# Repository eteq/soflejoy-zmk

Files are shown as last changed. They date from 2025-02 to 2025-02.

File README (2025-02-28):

# Soflejoy

This is a mod on a Sofle Choc keyboard that replaces the right-side encoder with a joystick.  The PCB layout for the adapter board is a KiCad PCB in ``joystick_encoder_adapter``. The joystick is a FJ06K-S joystick and you can just solder that into the adapter board and then use short lengths of wire to connect the adapter to the encoder footprint. Note, though, there is not a power pin available on the existing Sofle layout, so you will need to do a little bodge wire connecting the 3V pad on the adapter to the nearby 3V pad for the power jack that connects the two halves of the keyboard.

## Building

In zmk dir, start devcontainer as:

% devcontainer up --workspace-folder ~/src/zmk && devcontainer exec --workspace-folder ~/src/zmk bash

Then in the devcontainer:

% cd app
% west build -d build/left -b nice_nano_v2 -- -DSHIELD=soflejoy_left -DZMK_CONFIG=/workspaces/zmk-config -DZMK_EXTRA_MODULES=/workspaces/zmk-config && west build -d build/right -b nice_nano_v2 -- -DSHIELD=soflejoy_right -DZMK_CONFIG=/workspaces/zmk-config -DZMK_EXTRA_MODULES=/workspaces/zmk-config

But that only works if the zmk-config volume is set up to point to this directory.

## Joystick calibration

For in-min/max/deadzone values I set are probably dependent on the specific joystick. To determine them I compiled the right board with ``-S zmk-usb-logging``, set ``config INPUT_LOG_LEVEL=4`` in the defconfig, and then fiddled with the joystick while saving out the ttyACM0 output.  I then parsed the raw values with some manual python to get the resulting values. For my particular joystick I saw:

* both x and y would max out at ~4000 if you just scrolled them, but if you wiped them, went up to ~4050
* x and y both mined out within 10 or so of 0, although x consistently at -3, and y either 10 or -3 depending on wiping
* x at center seemed to be 2010 - 2030
* y at center seemed to be 1780 - 2100 - i.e. didn't bounce back to the same spot
* std at stability was ~4

## Modifying the keymap

The keymap is configured via the ``boards/shields/soflejoy/sofle_keymaps.xlsx file``.  Once updated, run ``python make_map.py -f sofle_keymaps.xlsx > soflejoy.keymap`` to update the keymap.

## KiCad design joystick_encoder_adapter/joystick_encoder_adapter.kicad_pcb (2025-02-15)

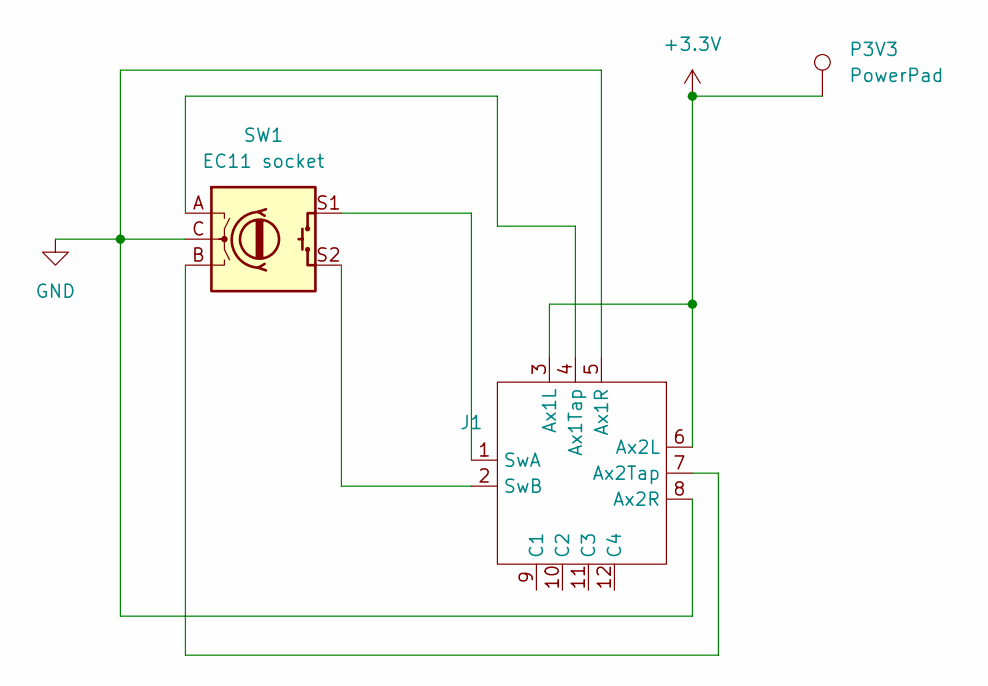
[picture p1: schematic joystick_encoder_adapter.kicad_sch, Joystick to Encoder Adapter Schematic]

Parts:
J1: FJ06K
P3V3: PowerPad; TestPoint_THTPad_D2.0mm_Drill1.0mm
SW1: EC11 socket; ec11e_from_sofle_nomp

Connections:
+3.3V: J1.3 (Ax1L), J1.6 (Ax2L), P3V3.1
GND: J1.5 (Ax1R), J1.8 (Ax2R), SW1.C
unnamed: J1.4 (Ax1Tap), SW1.A
unnamed: J1.7 (Ax2Tap), SW1.B
unnamed: J1.1 (SwA), SW1.S1
unnamed: J1.2 (SwB), SW1.S2

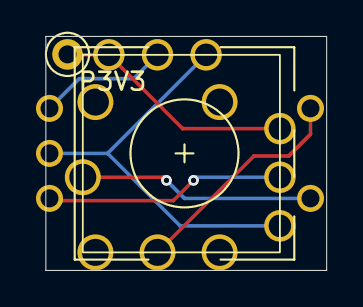
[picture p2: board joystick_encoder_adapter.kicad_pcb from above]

Board: 2 copper layers, 15.6 x 13.0 mm, 3 parts (0 on the bottom side), 6 nets.

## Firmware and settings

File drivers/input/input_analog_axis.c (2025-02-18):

/*
 * Copyright 2023 Google LLC
 *
 * SPDX-License-Identifier: Apache-2.0
 */

#define DT_DRV_COMPAT analog_axis

#include <stdlib.h>
#include <zephyr/device.h>
#include <zephyr/drivers/adc.h>
#include <zephyr/input/input.h>
#include <zephyr/input/input_analog_axis.h>
#include <zephyr/kernel.h>
#include <zephyr/logging/log.h>
#include <zephyr/pm/device.h>
#include <zephyr/pm/device_runtime.h>
#include <zephyr/sys/atomic.h>
#include <zephyr/sys/util.h>

LOG_MODULE_REGISTER(analog_axis, CONFIG_INPUT_LOG_LEVEL);

struct analog_axis_channel_config {
	struct adc_dt_spec adc;
	int16_t out_min;
	int16_t out_max;
	uint16_t axis;
	bool invert_input;
	bool invert_output;
	bool relative_axis;
};

struct analog_axis_channel_data {
	int last_out;
};

struct analog_axis_config {
	uint32_t poll_period_ms;
	const struct analog_axis_channel_config *channel_cfg;
	struct analog_axis_channel_data *channel_data;
	struct analog_axis_calibration *calibration;
	const uint8_t num_channels;
};

struct analog_axis_data {
	struct k_sem cal_lock;
	analog_axis_raw_data_t raw_data_cb;
	struct k_timer timer;
	struct k_thread thread;

	K_KERNEL_STACK_MEMBER(thread_stack,
			      CONFIG_INPUT_ANALOG_AXIS_THREAD_STACK_SIZE);

#ifdef CONFIG_PM_DEVICE
	atomic_t suspended;
	struct k_sem wakeup;
#endif
};

int analog_axis_num_axes(const struct device *dev)
{
	const struct analog_axis_config *cfg = dev->config;

	return cfg->num_channels;
}

int analog_axis_calibration_get(const struct device *dev,
				int channel,
				struct analog_axis_calibration *out_cal)
{
	const struct analog_axis_config *cfg = dev->config;
	struct analog_axis_data *data = dev->data;
	struct analog_axis_calibration *cal = &cfg->calibration[channel];

	if (channel >= cfg->num_channels) {
		return -EINVAL;
	}

	k_sem_take(&data->cal_lock, K_FOREVER);
	memcpy(out_cal, cal, sizeof(struct analog_axis_calibration));
	k_sem_give(&data->cal_lock);

	return 0;
}

void analog_axis_set_raw_data_cb(const struct device *dev, analog_axis_raw_data_t cb)
{
	struct analog_axis_data *data = dev->data;

	k_sem_take(&data->cal_lock, K_FOREVER);
	data->raw_data_cb = cb;
	k_sem_give(&data->cal_lock);
}

int analog_axis_calibration_set(const struct device *dev,
				int channel,
				struct analog_axis_calibration *new_cal)
{
	const struct analog_axis_config *cfg = dev->config;
	struct analog_axis_data *data = dev->data;
	struct analog_axis_calibration *cal = &cfg->calibration[channel];

	if (channel >= cfg->num_channels) {
		return -EINVAL;
	}

	k_sem_take(&data->cal_lock, K_FOREVER);
	memcpy(cal, new_cal, sizeof(struct analog_axis_calibration));
	k_sem_give(&data->cal_lock);

	return 0;
}

static int32_t analog_axis_out_deadzone(const struct device *dev,
					int channel,
					int32_t raw_val)
{
	const struct analog_axis_config *cfg = dev->config;
	const struct analog_axis_channel_config *axis_cfg = &cfg->channel_cfg[channel];
	struct analog_axis_calibration *cal = &cfg->calibration[channel];

	int16_t in_range = cal->in_max - cal->in_min;
	int16_t out_range = axis_cfg->out_max - axis_cfg->out_min;
	int16_t in_mid = DIV_ROUND_CLOSEST(cal->in_min + cal->in_max, 2);
	int16_t in_min = cal->in_min;

	if (abs(raw_val - in_mid) < cal->in_deadzone) {
		return DIV_ROUND_CLOSEST(axis_cfg->out_max + axis_cfg->out_min, 2);
	}

	in_range -= cal->in_deadzone * 2;
	in_min += cal->in_deadzone;
	if (raw_val < in_mid) {
		raw_val += cal->in_deadzone;
	} else {
		raw_val -= cal->in_deadzone;
	}

	return DIV_ROUND_CLOSEST((raw_val - in_min) * out_range, in_range) + axis_cfg->out_min;
}

static int32_t analog_axis_out_linear(const struct device *dev,
				      int channel,
				      int32_t raw_val)
{
	const struct analog_axis_config *cfg = dev->config;
	const struct analog_axis_channel_config *axis_cfg = &cfg->channel_cfg[channel];
	struct analog_axis_calibration *cal = &cfg->calibration[channel];

	int16_t in_range = cal->in_max - cal->in_min;
	int16_t out_range = axis_cfg->out_max - axis_cfg->out_min;

	return DIV_ROUND_CLOSEST((raw_val - cal->in_min) * out_range, in_range) + axis_cfg->out_min;
}

static void analog_axis_loop(const struct device *dev)
{
	const struct analog_axis_config *cfg = dev->config;
	struct analog_axis_data *data = dev->data;
	int16_t bufs[cfg->num_channels];
	int32_t out;
	struct adc_sequence sequence = {
		.buffer = bufs,
		.buffer_size = sizeof(bufs),
	};
	const struct analog_axis_channel_config *axis_cfg_0 = &cfg->channel_cfg[0];
	int err;
	int i;

	adc_sequence_init_dt(&axis_cfg_0->adc, &sequence);

	for (i = 0; i < cfg->num_channels; i++) {
		const struct analog_axis_channel_config *axis_cfg = &cfg->channel_cfg[i];

		sequence.channels |= BIT(axis_cfg->adc.channel_id);
	}

	err = adc_read(axis_cfg_0->adc.dev, &sequence);
	if (err < 0) {
		LOG_ERR("Could not read (%d)", err);
		return;
	}

	k_sem_take(&data->cal_lock, K_FOREVER);

	for (i = 0; i < cfg->num_channels; i++) {
		const struct analog_axis_channel_config *axis_cfg = &cfg->channel_cfg[i];
		struct analog_axis_channel_data *axis_data = &cfg->channel_data[i];
		struct analog_axis_calibration *cal = &cfg->calibration[i];
		int32_t raw_val = bufs[i];

		if (axis_cfg->invert_input) {
			raw_val *= -1;
		}

		if (data->raw_data_cb != NULL) {
			data->raw_data_cb(dev, i, raw_val);
		}

		LOG_DBG("%s: ch %d: raw_val: %d", dev->name, i, raw_val);

		if (cal->in_deadzone > 0) {
			out = analog_axis_out_deadzone(dev, i, raw_val);
		} else {
			out = analog_axis_out_linear(dev, i, raw_val);
		}

		out = CLAMP(out, axis_cfg->out_min, axis_cfg->out_max);

		if (axis_cfg->invert_output) {
			out = axis_cfg->out_max - out;
		}

		if (axis_cfg->relative_axis) {
			if (axis_data->last_out != 0 || out != 0) {  // not sure if the last out is needed
				input_report_rel(dev, axis_cfg->axis, out, true, K_FOREVER);
			}
		} else {
			if (axis_data->last_out != out) {
				input_report_abs(dev, axis_cfg->axis, out, true, K_FOREVER);
			}
		}
		axis_data->last_out = out;
	}

	k_sem_give(&data->cal_lock);
}

static void analog_axis_thread(void *arg1, void *arg2, void *arg3)
{
	const struct device *dev = arg1;
	const struct analog_axis_config *cfg = dev->config;
	struct analog_axis_data *data = dev->data;
	int err;
	int i;

	for (i = 0; i < cfg->num_channels; i++) {
		const struct analog_axis_channel_config *axis_cfg = &cfg->channel_cfg[i];

		if (!adc_is_ready_dt(&axis_cfg->adc)) {
			LOG_ERR("ADC controller device not ready");
			return;
		}

		err = adc_channel_setup_dt(&axis_cfg->adc);
		if (err < 0) {
			LOG_ERR("Could not setup channel #%d (%d)", i, err);
			return;
		}
	}

	while (true) {
#ifdef CONFIG_PM_DEVICE
		if (atomic_get(&data->suspended) == 1) {
			k_sem_take(&data->wakeup, K_FOREVER);
		}
#endif

		analog_axis_loop(dev);
		k_timer_status_sync(&data->timer);
	}
}

static int analog_axis_init(const struct device *dev)
{
	struct analog_axis_data *data = dev->data;
	k_tid_t tid;

	k_sem_init(&data->cal_lock, 1, 1);
	k_timer_init(&data->timer, NULL, NULL);
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

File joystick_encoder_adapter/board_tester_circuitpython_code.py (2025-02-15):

import time
import board
import analogio
import digitalio
import neopixel

a5 = analogio.AnalogIn(board.AIN5) #P0_29
a7 = analogio.AnalogIn(board.AIN7) #P0_31

gpout = digitalio.DigitalInOut(board.P0_02).switch_to_output(True) # row0
gpin = digitalio.DigitalInOut(board.P0_24) #col0
gpin.switch_to_input(pull=digitalio.Pull.DOWN)

printtype = 'neopixel'

if printtype == 'neopixel':
    pixel_pin = board.P0_06
    num_pixels = 29
    npx = neopixel.NeoPixel(pixel_pin, num_pixels, brightness=.05)

i = 0
while True:
    if printtype == 'v':
        a5v = a5.reference_voltage*a5.value*2**-16
        a7v = a7.reference_voltage*a7.value*2**-16
        print(f'a5,7: {a5v:.3f} {a7v:.3f}')
    elif printtype == '12bit':
        a5v = a5.value//16
        a7v = a7.value//16
        print(f'a5,7: {a5v:04} {a7v:04}')
    elif printtype == 'raw':
        print(f'a5,7: {a5.value:05} {a7.value:05}')
    elif printtype == 'neopixel':
        if i % 2 == 0:
            print('npx on')
            npx.fill((100, 0, 255))
        else:
            print('npx off')
            npx.fill((0, 0, 0))
    else:
        print('gpio is', gpin.value)
    time.sleep(.1)
    i += 1

# 5/29 is Y, observed range in 12bit is roughly 4030 - ~0 for down-up
# 7/31 is X, observed range in 12bit is roughly 0 - 4040 for left-right
# for both it seems like 4000 is more the limit unless you brush around a bit

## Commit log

2025-02-09 initial import from testing zmk branch
    note that this is actually the contents of a separate branch
    eteq/zmk@eriks_custom, SHA f817a88fcb2073223114d52b8043c3019313654f,
    but it was going to screw up history a lot to try to merge that in
    here.
    [sofle_keymaps.xlsx]
2025-02-15 add joystick encoder adapter
    [joystick_encoder_adapter.kicad_pcb, joystick_encoder_adapter.kicad_sch]
2025-02-28 working stick
    [sofle_keymaps.xlsx]
2025-03-02 improve joystick behavior
    [sofle_keymaps.xlsx]
2025-03-02 fix for adc behavior (requiring manual patch)
